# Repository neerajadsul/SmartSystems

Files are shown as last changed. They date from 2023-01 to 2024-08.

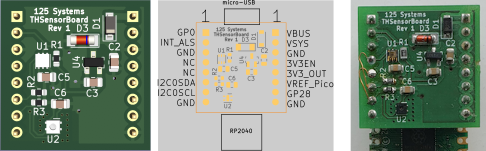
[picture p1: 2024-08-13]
SensorNetwork/figures/board_views.png

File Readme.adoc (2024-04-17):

# Temperature, Humidity, Ambient Light Monitoring
ifdef::env-name[:relfilesuffix: .adoc]

The goal of this project is to design a temperature and humidity monitoring system for indoor home usage.

## Specifications
. Monitor the temperature (T) in deg celsius with accuracy of better than 1%.
. Monitor the humidity (RH) in %RH (relative humidity) with accuracy of better than 5%.
. Monitor the ambient light in relative lux (LUX) with respect to dark.
. Capable of recording the T, RH, LUX at least once every 30 seconds.
. Records T, RH, LUX in a database.
. Presents T, RH, LUX data as a time-series via a web-interface.
. The web-interface is accesible atleast within the intra-net.

## System Design
A block diamgram of the system is shown in the figure below.

Home Monitoring Systems Block Diagram

## Hardware Design
The sensor board has Sensirion SHTC3 temperature and humidity sensor.
The board is designed to fit on top or under of the Raspberry Pi Pico W (PicoW).

Sensorboard for Temperature

## Software Design

### Monitoring Server
The monitoring server is deployed on a Raspberry Pi 400.
The sensor node communicates to a Python Django based web-app which can receive data on port 8080.
The web app stores data in a SQLite database. The database backup is scheduled for everyday on a internal network attached storage.

#### Web API Specifications

Web API specifications are documented in xref:SensorNetwork/WebAPISpecifications.adoc[Web API Specifications]
# Web API Specifications

## Sensor Node
### Send Monitoring Data Point
* Sensor Node sends the data with a `<POST>` request.
* Endpoint: `/thlmonitor/sensor_data`
* Send data in as Python dictionary. Individual fields are listed below:
** `location` sent as a tuple of grid co-ordinates as per the sensor grid specifications
** `timestamp` sent as a of tuple of `time.localtime()`
** Temperature `T` sent as a number with one decimal precision.
** Relative Humidity `RH` sent as a an integer number between [0, 100].
** Ambient Light intensity `LUX` sent as a number with one decimal precision.

For example:
Ground floor, living room
[source, json] 
{"location":'0E4',"timestamp":(2023, 1, 15, 16, 47, 39, 6, 15),"T":23.5,"RH":50.5,"LUX":34.2}
OR
{"location":'GE4',"timestamp":(2023, 1, 15, 16, 47, 39, 6, 15),"T":23.5,"RH":50.5,"LUX":34.2}

First floor, N Office room
[source, json]
{"location":'1A6',"timestamp":(2023, 1, 15, 16, 47, 39, 6, 15),"T":23.5,"RH":50.5,"LUX":34.2}
OR
{"location":'FA6',"timestamp":(2023, 1, 15, 16, 47, 39, 6, 15),"T":23.5,"RH":50.5,"LUX":34.2}

### Get Current Time from Server
* Sensor requests current time with a `<GET>` request.
* Endpoint: `/thlmonitor/sensor_data`
** Data sent as number of seconds from epoch. 

### Example Sensor Grid Specifications

Sensor Grid for a Typical House

## User Front End for Home Monitoring
[TBD]

### Sensor Node
Programmers model for the sensor board is shown in following figure:

SensorBoard connections to Pico W

* Each sensor node consists of a PicoW as controller and THL sensor board.
* Each sensor node has a location tag to uniquely identify the location.
* PicoW sets up time of internal RTC clock
* PicoW uses MicroPython with urequest library
* Each of the Sensirion T/RH and LiteOn Ambient light sensor communicates with PicoW via I2C interface.
* The sensor node acquires T, RH and LUX data every 30 seconds and puts it in a queue.
* The node attempts to send the data in queue to the server in JSON format specified above.
If successful the datapoint is dequeued, else attempted again.

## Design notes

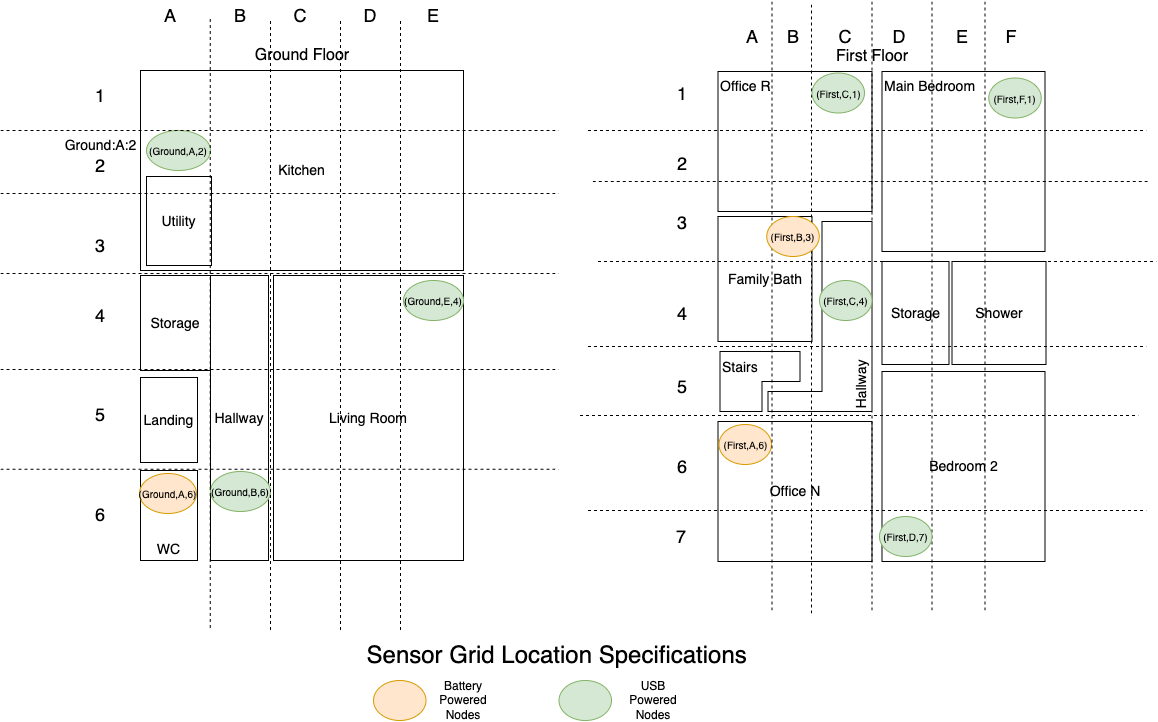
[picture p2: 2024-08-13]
SensorNetwork/figures/SensorGridSpecification.png

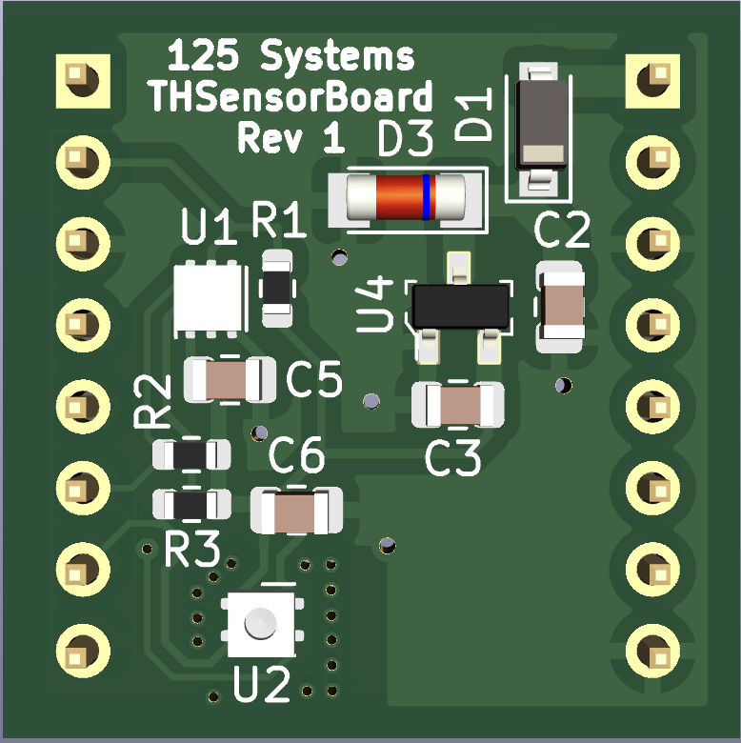
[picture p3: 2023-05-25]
SensorNetwork/figures/THLSensorBoard.png

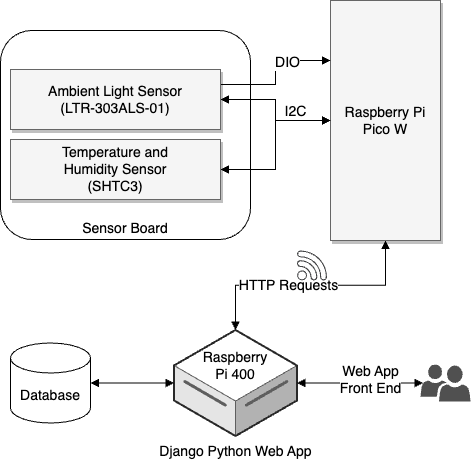
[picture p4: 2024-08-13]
SensorNetwork/figures/SystemBlockDiagram.png

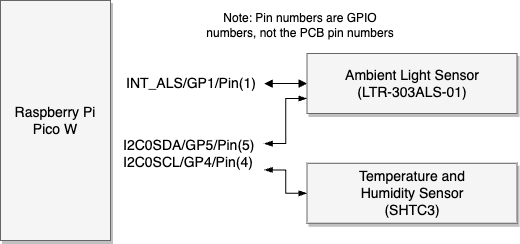
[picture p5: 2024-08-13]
SensorNetwork/figures/FirmwareProgrammersModel.png

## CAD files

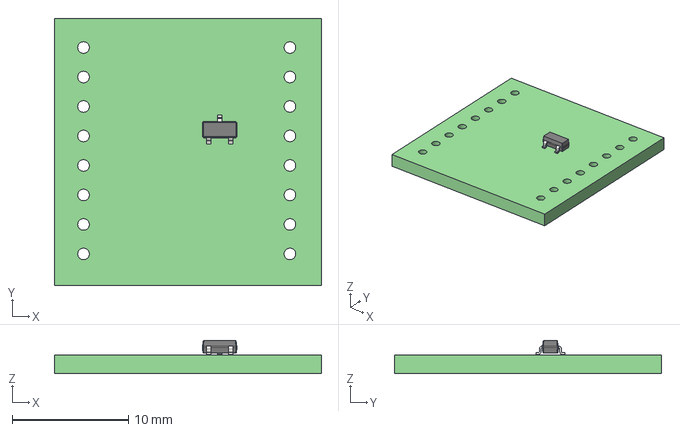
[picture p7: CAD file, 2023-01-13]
SensorNetwork/SensorBoard/SensorBoard.step
23.0 x 23.0 x 2.85 mm
SensorBoard PCB

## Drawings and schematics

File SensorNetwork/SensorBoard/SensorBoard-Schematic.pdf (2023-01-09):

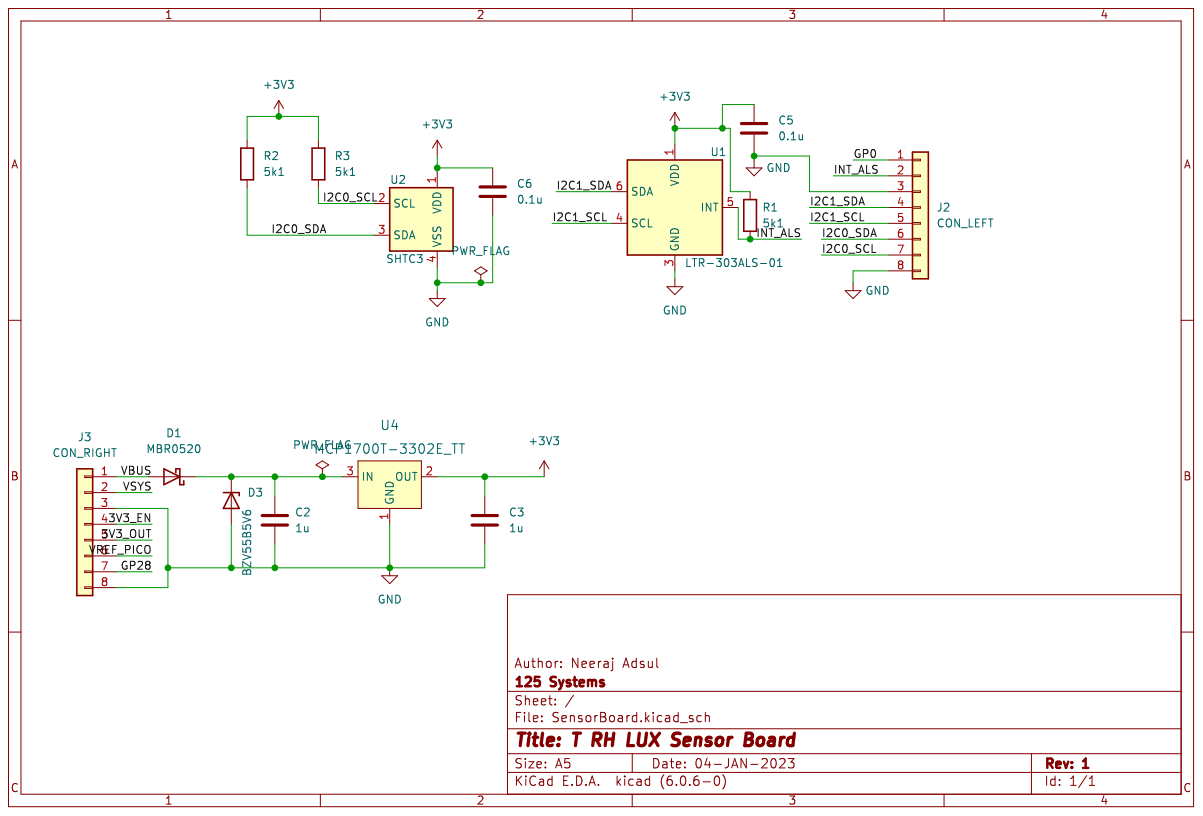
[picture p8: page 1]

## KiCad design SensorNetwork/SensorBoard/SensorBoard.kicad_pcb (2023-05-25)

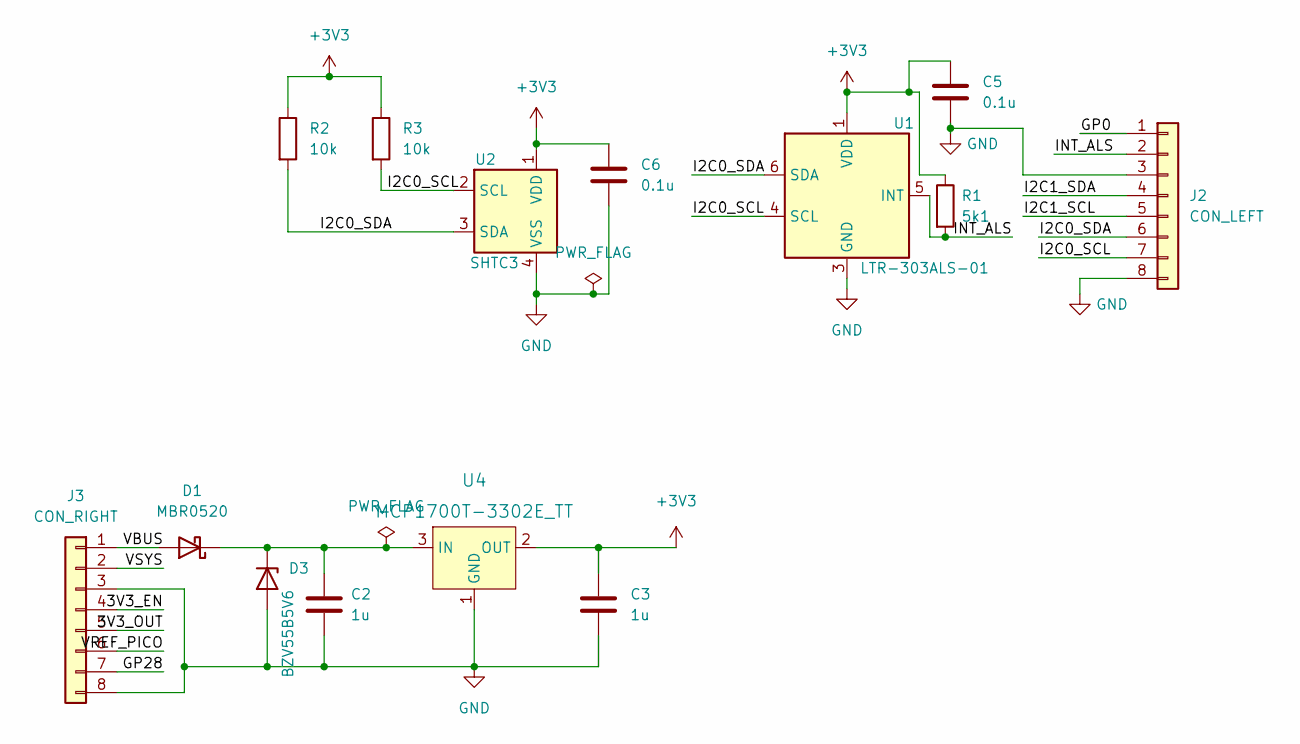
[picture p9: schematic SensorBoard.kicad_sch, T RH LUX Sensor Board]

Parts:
C2, C3: 1u; C_0805_2012Metric
C5, C6: 0.1u; C_0805_2012Metric
D1: MBR0520; D_SOD-123
D3: BZV55B5V6; D_MiniMELF
J2: CON_LEFT; PinHeader_1x08_P2.54mm_Vertical
J3: CON_RIGHT; PinHeader_1x08_P2.54mm_Vertical
R1: 5k1; R_0603_1608Metric
R2, R3: 10k; R_0603_1608Metric
U1: LTR-303ALS-01; Lite-On_LTR-303ALS-01
U2: SHTC3; Sensirion_DFN-4-1EP_2x2mm_P1mm_EP0.7x1.6mm
U4: MCP1700T-3302E_TT; SOT-23-3; MPN MCP1700T-3302E/TT; Digi-Key_PN MCP1700T3302ETTCT-ND

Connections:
+3V3: C3.1, C5.1, C6.1, R1.1, R2.1, R3.1, U1.1 (VDD), U2.1 (VDD), U4.2 (OUT)
/3V3_EN: J3.4
/3V3_OUT: J3.5
/GP0: J2.1
/GP28: J3.7
/I2C0_SCL: J2.7, R3.2, U1.4 (SCL), U2.2 (SCL)
/I2C0_SDA: J2.6, R2.2, U1.6 (SDA), U2.3 (SDA)
/I2C1_SCL: J2.5
/I2C1_SDA: J2.4
/INT_ALS: J2.2, R1.2, U1.5 (INT)
/VBUS: D1.2 (A), J3.1
/VREF_PICO: J3.6
/VSYS: J3.2
GND: C2.2, C3.2, C5.2, C6.2, D3.2 (A), J2.3, J2.8, J3.3, J3.8, U1.3 (GND), U2.4 (VSS), U4.1 (GND)
unnamed: C2.1, D1.1 (K), D3.1 (K), U4.3 (IN)

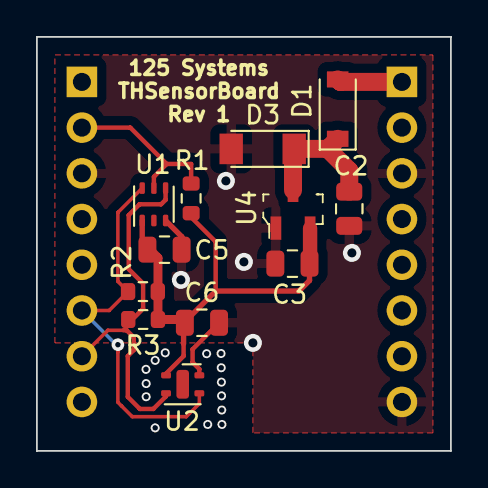
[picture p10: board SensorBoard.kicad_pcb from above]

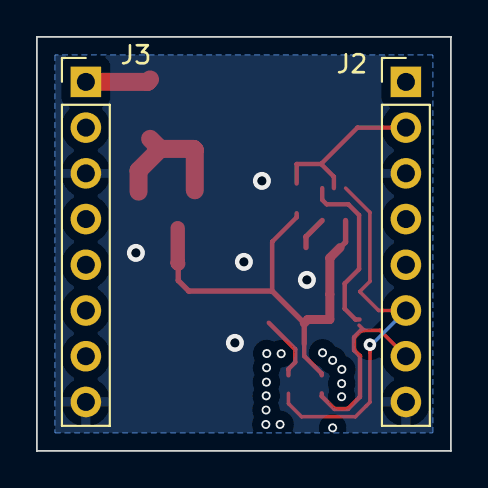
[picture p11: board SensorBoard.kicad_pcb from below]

Board: 2 copper layers, 23.0 x 23.0 mm, 14 parts (2 on the bottom side), 7 nets.

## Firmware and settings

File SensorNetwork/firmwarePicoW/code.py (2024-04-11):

import time
import board
from adafruit_shtc3 import SHTC3
from adafruit_ltr329_ltr303 import LTR303
import busio
import bitbangio
from digitalio import Pull, DigitalInOut
import wifi
import os
import socketpool
import adafruit_requests
import rtc

real_time_clock = rtc.RTC()

class THLData():
    def __init__(self, location, timesecs, T, RH, LUX):
        self.location = location
        self.timesecs = timesecs
        self.T = T
        self.RH = RH
        self.LUX = LUX

    def __str__(self):
        return "{" + f'''"location":'{self.location}',"timesecs":{self.timesecs},"T":{self.T},"RH":{self.RH},"LUX":{self.LUX}''' + "}"

def get_als_reading(ltr303):
    while True:
        ltr303.throw_out_reading()
        if ltr303.new_als_data_available:
            ltr303.throw_out_reading()
            if ltr303.als_data_invalid:
                ltr303.throw_out_reading()
                continue
        for i in range(2):
            lux_visible = ltr303.visible_plus_ir_light
            lux_ir = ltr303.ir_light
        # print("VisibleIR: %.1f, IR: %.1f" % (lux_visible, lux_ir))
        break
    return (lux_visible, lux_ir)

def get_sht_reading(sht):
    T, RH = sht.measurements
    return T, RH

def send_data(sht, ltr303, requests, homewatcher_server):
    T, RH = get_sht_reading(sht)
    print("T: %0.1fC, H: %0.1f %%" % (T, RH))

    als_data = get_als_reading(ltr303)
    print("LTR: ", als_data)

    thl_data = THLData(
            os.getenv("LOCATION"),
            time.time(),
            T,
            RH,
            als_data
        )
    print(str(thl_data))
    try:
        response = requests.post(homewatcher_server, data=str(thl_data))
        print(response.text)
    except:
        pass

def main():
    # URL endpoint in settings.toml file
    homewatcher_server = os.getenv("URL_ENDPOINT_SENSOR_DATA")


    print("Connecting to Wi-Fi")
    status = wifi.radio.connect(
        os.getenv("CIRCUITPY_WIFI_SSID"),
        os.getenv("CIRCUITPY_WIFI_PASSWORD")
        )

    pool = socketpool.SocketPool(wifi.radio)
    print("IP Address:", wifi.radio.ipv4_address)

    requests = adafruit_requests.Session(pool)

    i2c = busio.I2C(
            board.GP5, board.GP4
        )

    # SHTC3 Temperature Humidity Sensor
    sht = SHTC3(i2c)

    # LTR-303ALS-01 Sensor
    ltr303 = LTR303(i2c)
    ltr303.als_gain = 96
    ltr303.integration_time = 100
    ltr303.measurement_rate = 200
    als_data = get_als_reading(ltr303)
    time.sleep(0.2)

    # GET request obtains timesecs, current time as integer
    try:
        response = requests.get(homewatcher_server)
        time.sleep(5)
        print(response.text)
        tt = int(response.text)
    except:
        print("GET request failed")
    else:
        real_time_clock.datetime = time.localtime(tt)
    packet_count = 0
    while True:
        send_data(sht, ltr303, requests, homewatcher_server)
        # packet_count += 1
        #if packet_count > 5:
        #    break
        time.sleep(10)

if __name__ == "__main__":
    main()

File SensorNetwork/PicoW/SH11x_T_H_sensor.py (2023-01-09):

import time
from machine import Pin, RTC


ON = True
OFF = False
HIGH = 1
LOW = 0

#  Power to SHT1x, active Low, via MOSFET
en_SHT1x = Pin(6, Pin.OUT)
#  SCLK clock pin to SHT1x
SCLK = Pin(8, Pin.OUT)
# DATA pin to SHT1x
DATA = Pin(7, Pin.OPEN_DRAIN)
rtc = RTC()

def init_SHT1x_interface():
    # Initialise the pins
    en_SHT1x.value(1)
    SCLK.low()
    DATA.high()
    time.sleep(1)

def SHT1x_power(status):
    if status:
        # Power OFF SHT1x via MOSFET
        en_SHT1x.low()
    else:
        # Power ON SHT1x via MOSFET
        en_SHT1x.high()
    time.sleep_ms(20)
    

def SHT1x_soft_reset():
    """  """
    # 3 address bits, 5 command bits
    command = 0b000_11110
    send_command_ackn(command)
    time.sleep_ms(20)
 
    
def transmission_start():
    """Transmission Start Sequence for SHT1x"""
    SCLK.high()
    time.sleep_us(100)
    DATA.low()
    time.sleep_us(50)
    SCLK.low()
    time.sleep_us(100)
    SCLK.high()
    time.sleep_us(100)
    DATA.high()
    time.sleep_us(50)
    SCLK.high()
    time.sleep_us(100)


def send_command_ackn(command):
    """ Bit-bang the command, msb first; wait for acknowlegement"""    
    mask = 0b1000_0000
    for idx in range(8):
        SCLK.low()
        time.sleep_us(100)
        DATA.value((mask >> idx) & command)
        time.sleep_us(50)
        SCLK.high()
        time.sleep_us(100)
    # Release data line
    DATA.value(1)
    # Clock pulse for ACK
    for i in range(3):        
        SCLK.value(i & 0b1)
        time.sleep_us(100)
     

def measure_temperature():
    # 3 address bits, 5 command bits
    command = 0b0000_0011
    send_command_ackn(command)


def measure_humidity():
    # 3 address bits, 5 command bits
    command = 0b000_00101
    send_command_ackn(command)


def read_data():
    data = 0x0000
    for idx in range(16, 8, -1):
        SCLK.high()
        time.sleep_us(100)
        data <<= 1
        data |= DATA.value()
        SCLK.low()
        time.sleep_us(100)
        
    # Clock pulse for ACK
    for i in range(1, 3):        
        SCLK.value(i & 0b1)
        time.sleep_us(100)
        
    for idx in range(7, -1, -1):
        SCLK.high()
        time.sleep_us(100)
        data <<= 1
        data |= DATA.value()
        SCLK.low()
        time.sleep_us(100)
    # Clock pulse for ACK
    for i in range(1, 3):        
        SCLK.value(i & 0b1)
        time.sleep_us(100)
        
    return data

def read_crc():
    crc = 0b0
    for idx in range(8):
        SCLK.value(1)
        time.sleep_us(100)
        crc <<= 1
        crc |= DATA.value()
        SCLK.value(0)
        time.sleep_us(100)
    # Clock pulse for ACK
    for i in range(1, 3):        
        SCLK.value(i & 0b1)
        time.sleep_us(100)
        
    return crc


init_SHT1x_interface()

SHT1x_power(ON)
transmission_start()
SHT1x_soft_reset()

for n in range(240):

    transmission_start()
    measure_temperature()
    for i in range(200):
        time.sleep_ms(2)
        if DATA.value() == 0:            
            break

    T_readout = read_data()
    temperature = -39.67 + (0.01 * T_readout)
    time.sleep_ms(10)
    
    transmission_start()
    measure_humidity()
    for i in range(200):
        time.sleep_ms(2)
        if DATA.value() == 0:            
            break
        
    H_readout = read_data()
    humidity = -2.0468 + (0.0367 * H_readout) + (-1.5955e-6 * (H_readout**2))
    true_humidity = (temperature - 25) * (0.01 + (0.00008 * humidity)) + humidity

    print(f"{rtc.datetime()}; {temperature}; {humidity}")
    print(f"{rtc.datetime()}; {T_readout}; {H_readout}")
    SHT1x_power(OFF)
    time.sleep(30)

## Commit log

2023-01-09 Starter draft of the sensor board
    [SensorBoard.kicad_pcb, SensorBoard.kicad_sch]
2023-01-09 Sensor board routed and checked
    [SensorBoard.kicad_pcb, SensorBoard.kicad_sch]
2023-01-09 Sensor board HTML interactive BOM
2023-01-09 Documentation and specifications
    [SensorBoard.kicad_sch]
2023-01-13 Documentions connections, local archive of 3d models, updates ibom
    [SensorBoard.kicad_pcb, SensorBoard.step]
2023-01-18 Sensor drivers, ALS works, SHT does not
2023-01-18 Corrects GPIO pin reference and adds correponding note
2023-01-20 SHT and LTR sensor functions with CircuitPython
2023-01-20 Removes prototype scripts to individually work the sensors
2023-03-01 view for getting sensor data
2023-03-01 updates url for endpoint to receive sensor data
2023-03-01 data models to store environmental data and sensor location
2023-03-01 migrations for evironmental data and sensor location
2023-04-26 Models to store Temperature, Humidity and Lighting data
2023-04-26 Registers models for Temperature, Humidity and Lighting data and sensor locations.
2023-04-26 Mechanism to receive sensor data point
2023-04-26 Draw schematic map of ground and first floor with HTML canvas
2023-04-26 Draws overlay of rooms layout and sensor grid.
2023-05-24 Fixes schematic and PCB, update corresponding figures
    [SensorBoard.kicad_pcb, SensorBoard.kicad_sch]
2023-05-25 Sends data obtained via I2C to server
2023-05-25 Updates format for sending sensor location to avoid conflict with tuple syntax
2024-04-11 Config changes to KiCAD 8
2024-04-11 Update board view to include all in a row.
2024-04-12 Send latest THL data to the template using json_script filter.
